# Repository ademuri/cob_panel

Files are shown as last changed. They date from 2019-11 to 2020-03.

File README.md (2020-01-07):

# cob_panel

This is a collection of designs for PCBs for the Colordance Circle project.

This is not an official Google open-source project.

## cob_2x2

`cob_2x2` is a 2x2 high-power RGB LED board. It uses the common WS2811 chip to control four "9W" RGB LEDs. These are the 700mA, 6-pin RGB LEDs found on Aliexpress et al. I'm using [these](https://www.aliexpress.com/item/32950854541.html?spm=a2g0s.9042311.0.0.17f04c4dzGsUTR), the "6Pin 9W RGB" version. These LEDs are controlled via the standard WS2812 one-wire protocol. The boards can be tiled into a 2x2 grid of boards, yielding a 4x4 grid of LEDs. The board-edge headers transmit power and signal. The boards also have an on-board Anderson PowerPole connector for 12v power, and a 1x02 header for LED signal in. An onboard jumper is used to control whether the LED signal is also chained through the board-edge header.

The pitch between LEDs is 80mm.

Note: this board is as-yet untested.

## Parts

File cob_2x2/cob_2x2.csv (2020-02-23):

Id | Designator | Package | Quantity | Designation | Supplier and ref
1 | H5,H4,H3,H2,H1 | HOLE_5MM_#8 | 5 | MountingHole
2 | D13,D12,D6,D2 | LED_RGB_EPISTAR_6PIN_RGB | 4 | LED_RGB
3 | JP1 | PinHeader_1x02_P2.54mm_Vertical | 1 | Jumper
4 | U31,U26,U11,U6 | TSSOP-8_3x3mm_P0.65mm | 4 | 3_Inverter
5 | U30,U28,U27,U23,U22,U10,U8,U7,U5,U3,U2 | SOT-25 | 11 | AL8860
6 | U29,U24,U9,U4 | SOP-8_3.76x4.96mm_P1.27mm | 4 | WS2811
7 | U25 | SOT-25 | 1 | AL8860_LED_DRIVER
8 | U1 | TSOT-23-5 | 1 | 5V_REG
9 | TH1 | R_1812_4532Metric | 1 | Thermistor_PTC
10 | R48,R47,R46,R40,R39,R38,R16,R15,R14,R8,R7,R6 | R_0603_1608Metric | 12 | 10k
11 | R45,R43,R41,R37,R35,R33,R13,R11,R9,R5,R3,R1 | R_0805_2012Metric | 12 | .143
12 | R42,R34,R10,R2 | R_0603_1608Metric | 4 | 33
13 | R4 | R_0603_1608Metric | 1 | 6k8
14 | L18,L17,L16,L15,L14,L13,L6,L5,L4,L3,L2,L1 | L_Taiyo-Yuden_NR-60xx | 12 | 47uH
15 | J5 | PinHeader_1x06_P2.54mm_Horizontal | 1 | Conn_01x06_Male
16 | J4 | PinSocket_1x06_P2.54mm_Horizontal | 1 | Conn_01x06_Female
17 | J3 | Anderson_1337G3_right_angle_bottom_two | 1 | Anderson_two_redblack
18 | J1 | PinHeader_1x02_P2.54mm_Vertical | 1 | Conn_01x02
19 | D24,D23,D21,D20,D19,D17,D8,D7,D5,D4,D3,D1 | D_SOD-123F | 12 | D_Schottky
20 | D11 | LED_0603_1608Metric_Pad1.05x0.95mm_HandSolder | 1 | LED
21 | D10 | SOD-923 | 1 | D_TVS_5V
22 | D9 | D_SOD-323_HandSoldering | 1 | D_TVS_12V
23 | C33,C32,C28,C27,C13,C12,C8,C7 | C_0603_1608Metric | 8 | .1uF
24 | C31,C30,C29,C26,C25,C24,C11,C10,C9,C6,C5,C4,C3,C1 | C_0805_2012Metric | 14 | 10uF

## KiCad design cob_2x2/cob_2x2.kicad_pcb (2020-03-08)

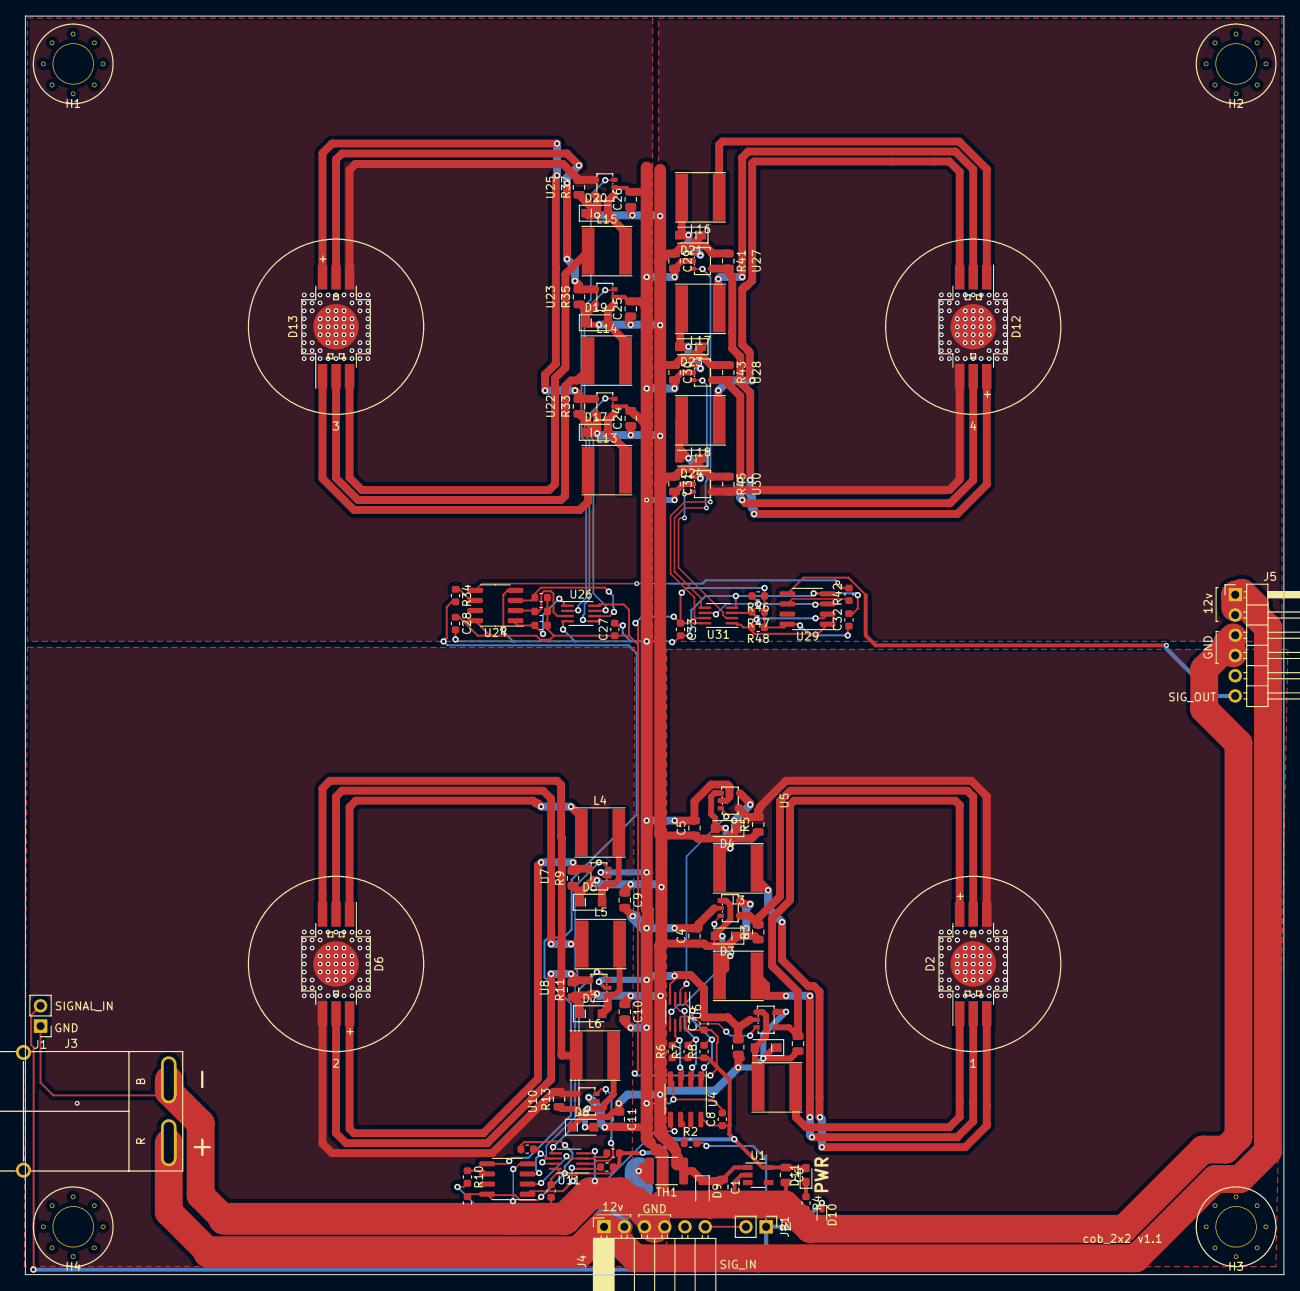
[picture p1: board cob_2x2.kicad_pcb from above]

Board: 2 copper layers, 158.0 x 158.0 mm, 113 parts (0 on the bottom side), 75 nets.

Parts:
C1, C3, C4, C5, C6, C9, C10, C11, C24, C25, C26, C29, C30, C31: 10uF; C_0805_2012Metric
C7, C8, C12, C13, C27, C28, C32, C33: .1uF; C_0603_1608Metric
D1, D3, D4, D5, D7, D8, D17, D19, D20, D21, D23, D24: D_Schottky; D_SOD-123F
D2, D6, D12, D13: LED_RGB; LED_RGB_EPISTAR_6PIN_RGB
D9: D_TVS_12V; D_SOD-323_HandSoldering
D10: D_TVS_5V; D_SOD-523
D11: LED; LED_0603_1608Metric_Pad1.05x0.95mm_HandSolder
H1, H2, H3, H4: MountingHole; HOLE_5MM_#8
J1: Conn_01x02; PinHeader_1x02_P2.54mm_Vertical
J3: Anderson_two_redblack; Anderson_1337G3_right_angle_bottom_two
J4: Conn_01x06_Female; PinSocket_1x06_P2.54mm_Horizontal
J5: Conn_01x06_Male; PinHeader_1x06_P2.54mm_Horizontal
JP1: Jumper; PinHeader_1x02_P2.54mm_Vertical
L1, L2, L3, L4, L5, L6, L13, L14, L15, L16, L17, L18: 47uH; L_Taiyo-Yuden_NR-60xx
R1, R3, R5, R9, R11, R13, R33, R35, R37, R41, R43, R45: .143; R_0805_2012Metric
R2, R10, R34, R42: 33; R_0603_1608Metric
R4: 6k8; R_0603_1608Metric
R6, R7, R8, R14, R15, R16, R38, R39, R40, R46, R47, R48: 10k; R_0603_1608Metric
TH1: Thermistor_PTC; R_1812_4532Metric
U1: 5V_REG_AP7370-50W5-7; TSOT-23-5
U2, U3, U5, U7, U8, U10, U22, U23, U25, U27, U28, U30: AL8860_LED_DRIVER; SOT-25
U4, U9, U24, U29: WS2811; SOP-8_3.76x4.96mm_P1.27mm
U6, U11, U26, U31: 3_Inverter_TC7WH14FU,LJ(CT; SSOP-8_2.95x2.8mm_P0.65mm

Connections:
12V_RAW: J3.1, J4.1, J4.2, J5.1, J5.2, TH1.2
+5V: C6.1, C7.1, C8.1, C12.1, C13.1, C27.1, C28.1, C32.1, C33.1, D11.2, R6.1, R7.1, R8.1, R14.1, R15.1, R16.1, R38.1, R39.1, R40.1, R46.1, R47.1, R48.1, U1.5, U4.8, U6.8, U9.8, U11.8, U24.8, U26.8, U29.8, U31.8
+12V: C1.1, C3.1, C4.1, C5.1, C9.1, C10.1, C11.1, C24.1, C25.1, C26.1, C29.1, C30.1, C31.1, D1.1, D3.1, D4.1, D5.1, D7.1, D8.1, D9.1, D17.1, D19.1, D20.1, D21.1, D23.1, D24.1, R1.1, R3.1, R5.1, R9.1, R11.1, R13.1, R33.1, R35.1, R37.1, R41.1, R43.1, R45.1, TH1.1, U1.1, U2.5, U3.5, U5.5, U7.5, U8.5, U10.5, U22.5, U23.5, U25.5, U27.5, U28.5, U30.5
/sheet5DF1A510/B_INVERTED: R38.2, U24.3, U26.6
/sheet5DF1A510/B_LED_A: D13.4, R37.2, U25.4
/sheet5DF1A510/B_LED_K: D13.3, L15.1
/sheet5DF1A510/B_SIGNAL: U25.3, U26.2
/sheet5DF1A510/G_INVERTED: R39.2, U24.2, U26.3
/sheet5DF1A510/G_LED_A: D13.5, R35.2, U23.4
/sheet5DF1A510/G_LED_K: D13.2, L14.1
/sheet5DF1A510/G_SIGNAL: U23.3, U26.5
/sheet5DF1A510/R_INVERTED: R40.2, U24.1, U26.1
/sheet5DF1A510/R_LED_A: D13.6, R33.2, U22.4
/sheet5DF1A510/R_LED_K: D13.1, L13.1
/sheet5DF1A510/R_SIGNAL: U22.3, U26.7
/sheet5DF1A510/SIGNAL_IN: R34.2, U9.5
/sheet5DF1FB98/B_INVERTED: R46.2, U29.3, U31.6
/sheet5DF1FB98/B_LED_A: D12.4, R45.2, U30.4
/sheet5DF1FB98/B_LED_K: D12.3, L18.1
/sheet5DF1FB98/B_SIGNAL: U30.3, U31.2
/sheet5DF1FB98/G_INVERTED: R47.2, U29.2, U31.3
/sheet5DF1FB98/G_LED_A: D12.5, R43.2, U28.4
/sheet5DF1FB98/G_LED_K: D12.2, L17.1
/sheet5DF1FB98/G_SIGNAL: U28.3, U31.5
/sheet5DF1FB98/R_INVERTED: R48.2, U29.1, U31.1
/sheet5DF1FB98/R_LED_A: D12.6, R41.2, U27.4
/sheet5DF1FB98/R_LED_K: D12.1, L16.1
/sheet5DF1FB98/R_SIGNAL: U27.3, U31.7
/sheet5DF1FB98/SIGNAL_IN: R42.2, U24.5
/sheet5DF187B4/B_INVERTED: R14.2, U9.3, U11.6
/sheet5DF187B4/B_LED_A: D6.4, R13.2, U10.4
/sheet5DF187B4/B_LED_K: D6.3, L6.1
/sheet5DF187B4/B_SIGNAL: U10.3, U11.2
/sheet5DF187B4/G_INVERTED: R15.2, U9.2, U11.3
/sheet5DF187B4/G_LED_A: D6.5, R11.2, U8.4
/sheet5DF187B4/G_LED_K: D6.2, L5.1
/sheet5DF187B4/G_SIGNAL: U8.3, U11.5
/sheet5DF187B4/R_INVERTED: R16.2, U9.1, U11.1
/sheet5DF187B4/R_LED_A: D6.6, R9.2, U7.4
/sheet5DF187B4/R_LED_K: D6.1, L4.1
/sheet5DF187B4/R_SIGNAL: U7.3, U11.7
/sheet5DF187B4/SIGNAL_IN: R10.2, U4.5
/single_led/B_INVERTED: R6.2, U4.3, U6.6
/single_led/B_LED_A: D2.4, R5.2, U5.4
/single_led/B_LED_K: D2.3, L3.1
/single_led/B_SIGNAL: U5.3, U6.2
/single_led/G_INVERTED: R7.2, U4.2, U6.3
/single_led/G_LED_A: D2.5, R3.2, U3.4
/single_led/G_LED_K: D2.2, L2.1
/single_led/G_SIGNAL: U3.3, U6.5
/single_led/R_INVERTED: R8.2, U4.1, U6.1
/single_led/R_LED_A: D2.6, R1.2, U2.4
/single_led/R_LED_K: D2.1, L1.1
/single_led/R_SIGNAL: U2.3, U6.7
GND: C1.2, C3.2, C4.2, C5.2, C6.2, C7.2, C8.2, C9.2, C10.2, C11.2, C12.2, C13.2, C24.2, C25.2, C26.2, C27.2, C28.2, C29.2, C30.2, C31.2, C32.2, C33.2, D9.2, D10.2, J1.1, J3.2, J4.3, J4.4, J5.3, J5.4, R4.2, U1.2, U2.2, U3.2, U4.4, U5.2, U6.4, U7.2, U8.2, U9.4, U10.2, U11.4, U22.2, U23.2, U24.4, U25.2, U26.4, U27.2, U28.2, U29.4, U30.2, U31.4
unnamed: D1.2, L1.2, U2.1
unnamed: D3.2, L2.2, U3.1
unnamed: D4.2, L3.2, U5.1
unnamed: D5.2, L4.2, U7.1
unnamed: D7.2, L5.2, U8.1
unnamed: D8.2, L6.2, U10.1
unnamed: D11.1, R4.1
unnamed: D17.2, L13.2, U22.1
unnamed: D19.2, L14.2, U23.1
unnamed: D20.2, L15.2, U25.1
unnamed: D21.2, L16.2, U27.1
unnamed: D23.2, L17.2, U28.1
unnamed: D24.2, L18.2, U30.1
unnamed: J4.6, JP1.2
unnamed: R2.1, U4.6
unnamed: R10.1, U9.6
unnamed: R34.1, U24.6
unnamed: R42.1, U29.6
SIGNAL_IN: D10.1, J1.2, JP1.1, R2.2
SIGNAL_OUT: J5.6, U29.5

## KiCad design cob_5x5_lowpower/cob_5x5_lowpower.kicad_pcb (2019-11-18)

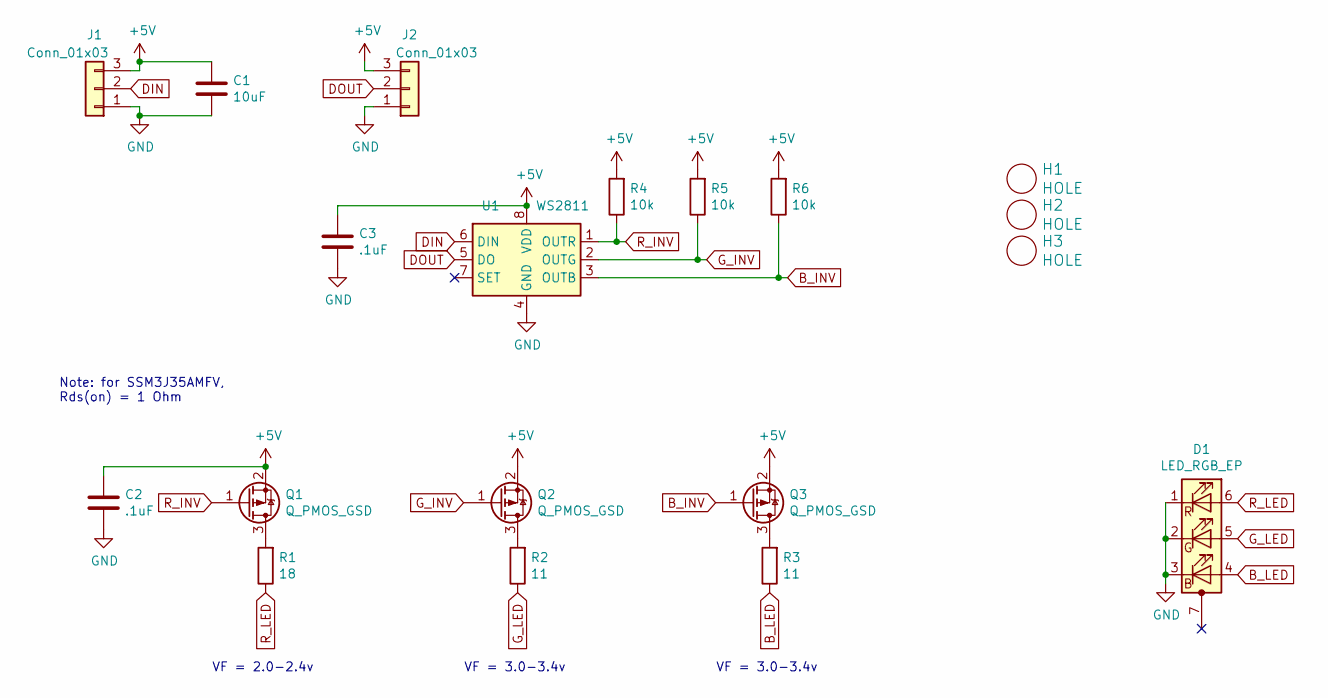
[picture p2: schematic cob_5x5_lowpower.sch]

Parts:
C1: 10uF; C_0805_2012Metric
C2, C3: .1uF; C_0603_1608Metric
D1: LED_RGB_EP; LED_RGB_EPISTAR_6PIN_RGB
H1, H2, H3: HOLE; MountingHole_2.7mm_M2.5
J1, J2: Conn_01x03; PinHeader_1x03_P2.54mm_Vertical
Q1, Q2, Q3: Q_PMOS_GSD; SOT-723
R1: 18; R_1210_3225Metric
R2, R3: 11; R_1210_3225Metric
R4, R5, R6: 10k; R_0603_1608Metric
U1: WS2811; SOP-8_3.76x4.96mm_P1.27mm

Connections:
+5V: C1.1, C2.1, C3.1, J1.3, J2.3, Q1.2 (S), Q2.2 (S), Q3.2 (S), R4.2, R5.2, R6.2, U1.8 (VDD)
B_INV: Q3.1 (G), R6.1, U1.3 (OUTB)
B_LED: D1.4 (BA), R3.1
DIN: J1.2, U1.6 (DIN)
DOUT: J2.2, U1.5 (DO)
GND: C1.2, C2.2, C3.2, D1.1 (RK), D1.2 (GK), D1.3 (BK), J1.1, J2.1, U1.4 (GND)
G_INV: Q2.1 (G), R5.1, U1.2 (OUTG)
G_LED: D1.5 (GA), R2.1
unnamed: Q1.3 (D), R1.2
unnamed: Q2.3 (D), R2.2
unnamed: Q3.3 (D), R3.2
R_INV: Q1.1 (G), R4.1, U1.1 (OUTR)
R_LED: D1.6 (RA), R1.1

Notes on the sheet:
Note: for SSM3J35AMFV, Rds(on) = 1 Ohm
VF = 2.0-2.4v
VF = 3.0-3.4v

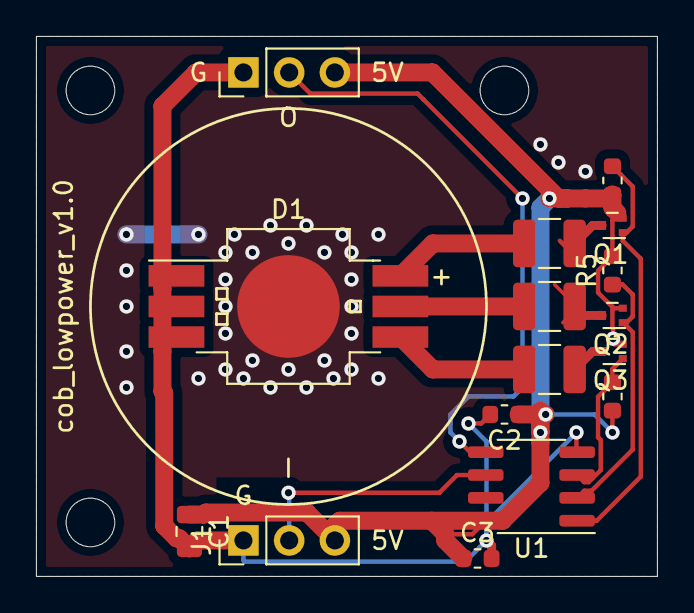
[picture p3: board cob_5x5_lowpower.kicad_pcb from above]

Board: 2 copper layers, 34.5 x 30.0 mm, 19 parts (0 on the bottom side), 13 nets.

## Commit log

2019-10-26 WIP add mini panel
    [cob_panel_mini.kicad_pcb, cob_panel_mini.sch]
2019-10-26 WIP associate footprints
    [cob_panel_mini.sch]
2019-10-26 WIP rev v1.0
    [cob_panel_mini.kicad_pcb, cob_single.kicad_pcb, cob_single.sch]
2019-10-29 Revision 1.0 with linear driver
    [cob_single-B_Cu.gbr, cob_single-B_Mask.gbr, cob_single-B_Paste.gbr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]
2019-10-31 Re-do revision 1.0 with 5V switching driver
    [cob_single.kicad_pcb, cob_single.sch]
2019-11-02 Convert v1.0 to 12v supply/12v tolerant switching driver.
    [cob_single-B_Cu.gbr, cob_single-B_Mask.gbr, cob_single-B_Paste.gbr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]
2019-11-07 Add 5x5 low power cob board
    [cob_5x5_lowpower-B_Cu.gbr, cob_5x5_lowpower-B_Fab.gbr, cob_5x5_lowpower-B_Mask.gbr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]
2019-11-18 High-power revision 1.1:
    - Fixed LED thermal pad to not connect to ground
    - Fixed clearance for LED lens
    - Added orientation for diodes and LED
    [cob_single-B_Cu.gbr, cob_single-B_Fab.gbr, cob_single-B_Mask.gbr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]
2019-11-18 Lowpower one-off revision 1.0.
    Updated previous attempt (unfabricated) with lessons from from
    high-power board.
    [cob_5x5_lowpower-B_Cu.gbr, cob_5x5_lowpower-B_Fab.gbr, cob_5x5_lowpower-B_Mask.gbr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]
2019-12-03 Add cob_3x3, create schematic for it
    [cob_3x3.kicad_pcb, cob_3x3.sch, single_led.sch]
2019-12-14 Add TVCs and power indicator to schematic.
    [cob_3x3.sch, single_led.sch]
2019-12-16 Schematic and footprints ready for v1.0:
    - Added board-to-board connectors for chaining a 2x2 array of 2x2
    boards.
    [cob_3x3.sch, single_led.sch]
2020-01-07 Hardware revision v1.0 complete
    [cob_2x2-B_Cu.gbr, cob_2x2-B_Fab.gbr, cob_2x2-B_Mask.gbr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]
2020-02-23 cob_2x2 v1.1:
    - Fix inverter footprint
    - Increase size of 5V TVS diode to SOD-523
    - Increase clearance for mounting holes by 1mm
    - Make mounting holes evenly spaced
    [cob_2x2-B_Cu.gbr, cob_2x2-B_Fab.gbr, cob_2x2-B_Mask.gbr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]
2020-03-08 Add Anderson connector 3d model
    [cob_2x2.kicad_pcb]
2021-06-14 Add HTML bom
